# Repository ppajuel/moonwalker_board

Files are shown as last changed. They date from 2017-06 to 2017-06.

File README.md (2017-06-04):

# moonwalker_board
Expansion board compatible with [Raspberry Pi 1 Modelo B](https://www.raspberrypi.org/products/model-b/)
 and [IGEP NEW YORK](https://isee.biz/products/igep-expansion-boards/igep-new-york) to control a RC CAR. Board Layout has been adapted to suite with [Nikko Mega Dominator](http://nikkoevolution.fr/voitures_et_pieces/568/Nikko-Mega-Dominator.html), but can be easily adaptable to another RC Car. Its features are:

* ATmega328 microcontroller: control all expansion board functionalities.
* Raspberry or IGEP boards (optional): control microcontroller through serial port.
* GPS expansion bus: [Adafruit Ultimate GPS Breakout](https://www.adafruit.com/product/746).
* Compass and accelerometer expansion bus: [Triple-axis Accelerometer+Magnetometer (Compass) Board - LSM303)](https://www.adafruit.com/product/1120).
* Gauge battery circuit.
* Servo and brushed motor drivers.
* Two independent power trees for electric motors and sensors&control.
* Atmega programer header.
* Hex segment display.

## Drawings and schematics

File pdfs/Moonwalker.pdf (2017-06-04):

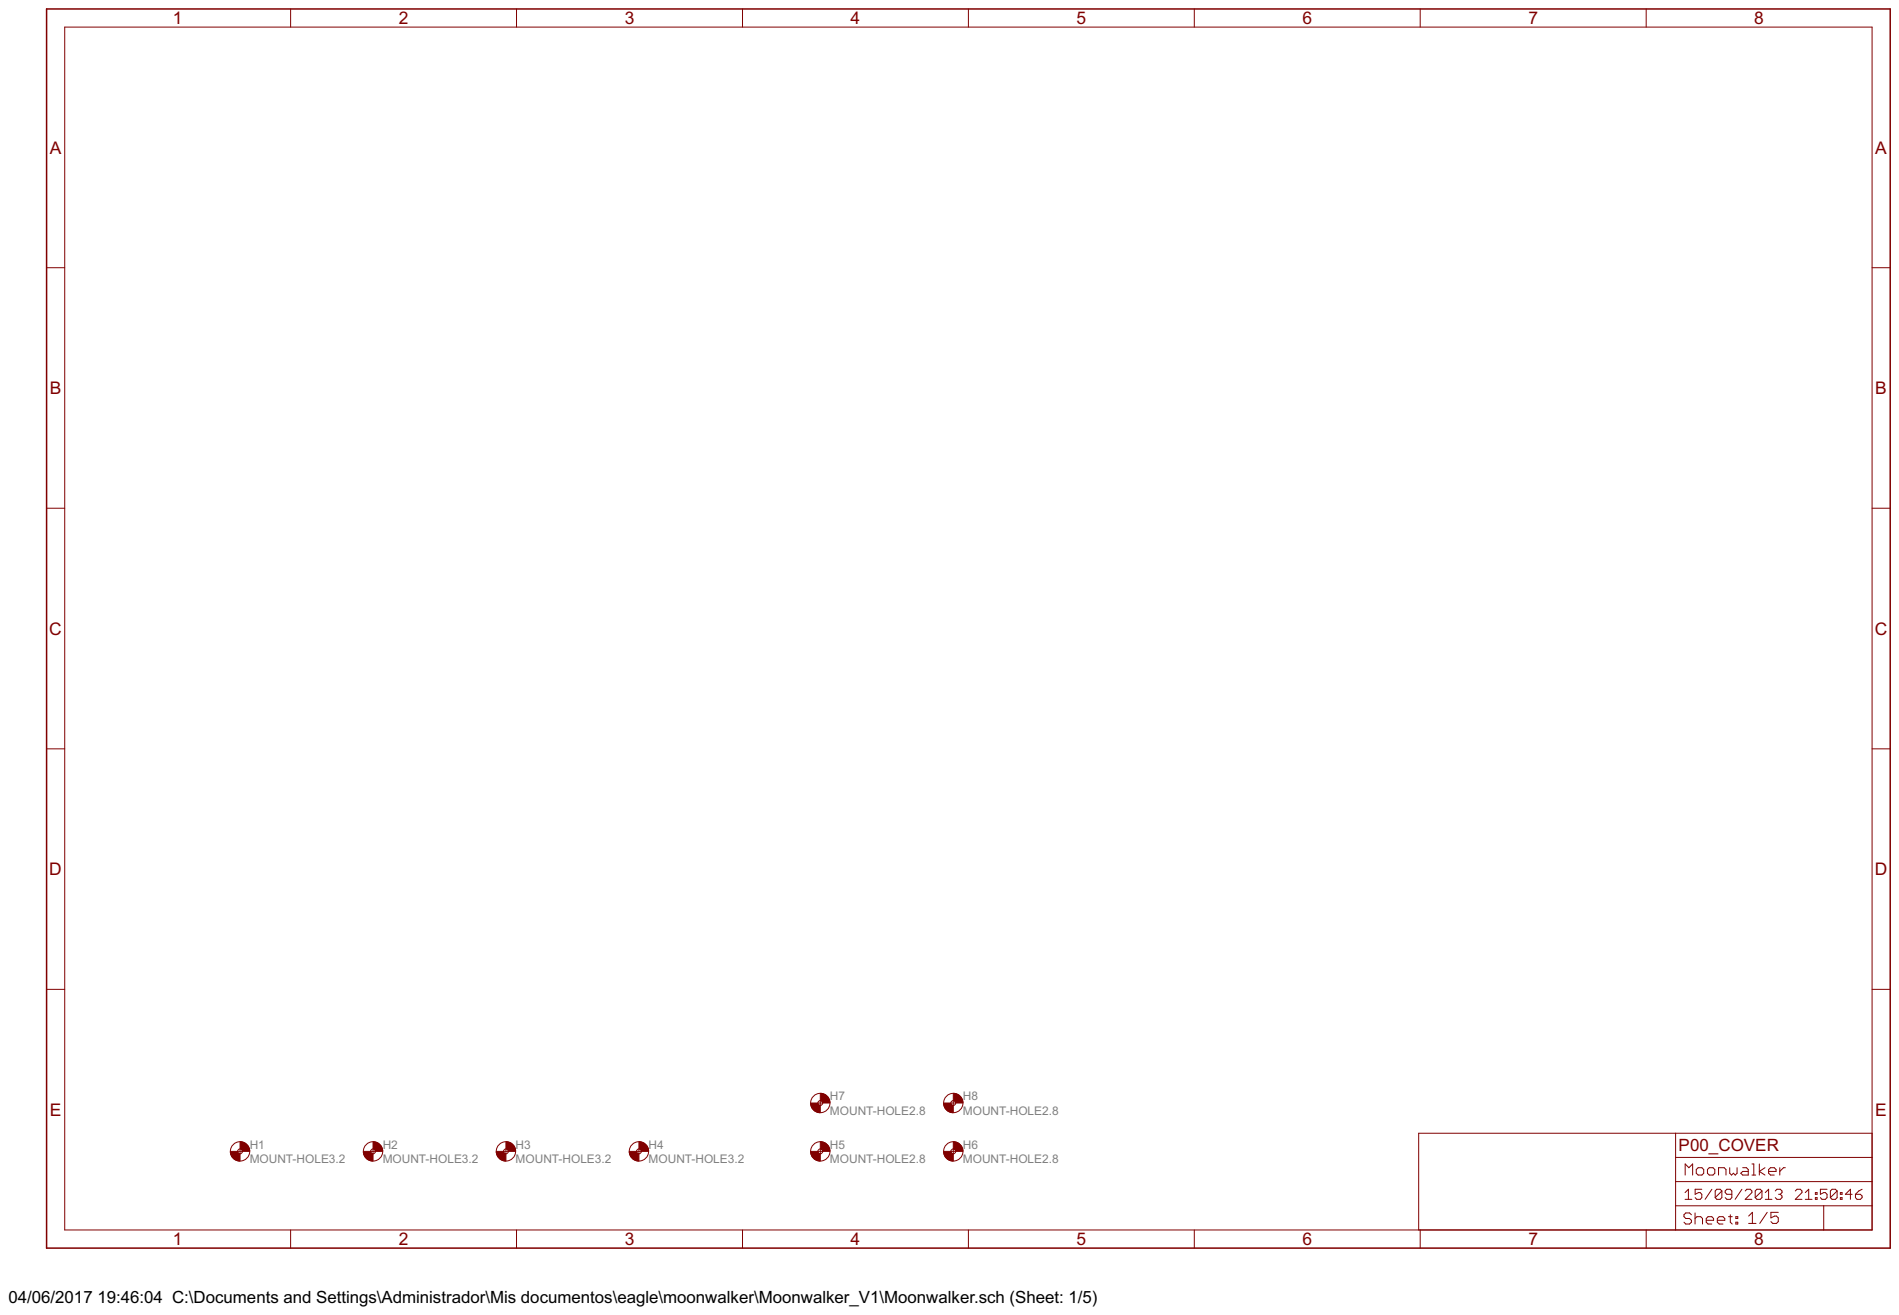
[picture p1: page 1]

04/06/2017 19:46:04 C:\Documents and Settings\Administrador\Mis documentos\eagle\moonwalker\Moonwalker_V1\Moonwalker.sch (Sheet: 1/5)

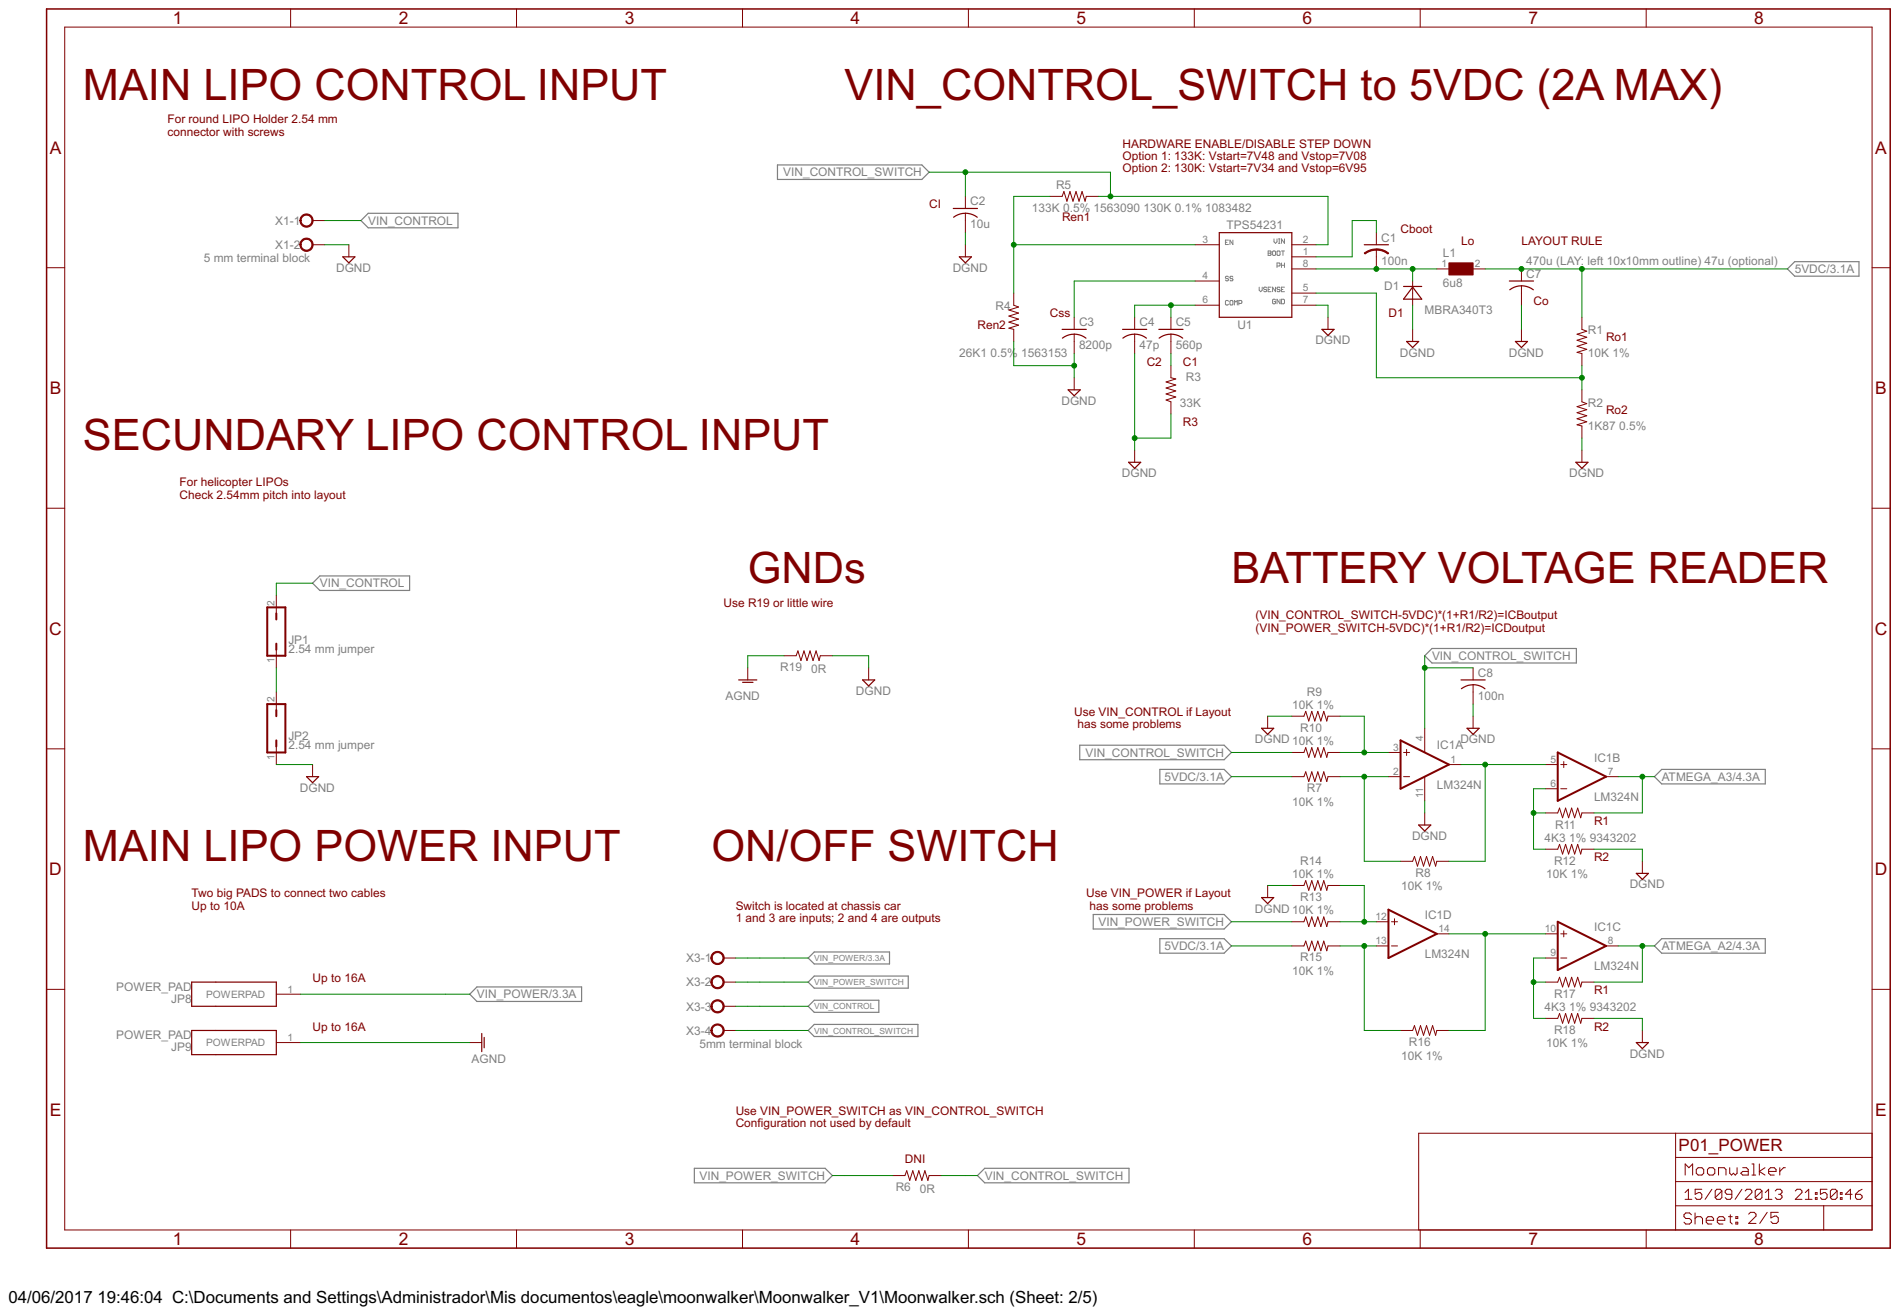
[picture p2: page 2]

MAIN LIPO CONTROL INPUT

For round LIPO Holder 2.54 mm
connector with screws

HARDWARE ENABLE/DISABLE STEP DOWN
Option 1: 133K: Vstart=7V48 and Vstop=7V08
Option 2: 130K: Vstart=7V34 and Vstop=6V95

LAYOUT RULE
470u (LAY: left 10x10mm outline) 47u (optional)

SECUNDARY LIPO CONTROL INPUT

For helicopter LIPOs Check 2.54mm pitch into layout

Use R19 or little wire

MAIN LIPO POWER INPUT

Two big PADS to connect two cables Up to 10A

1 and 3 are inputs; 2 and 4 are outputs

Use VIN_POWER_SWITCH as VIN_CONTROL_SWITCH
Configuration not used by default

04/06/2017 19:46:04 C:\Documents and Settings\Administrador\Mis documentos\eagle\moonwalker\Moonwalker_V1\Moonwalker.sch (Sheet: 2/5)

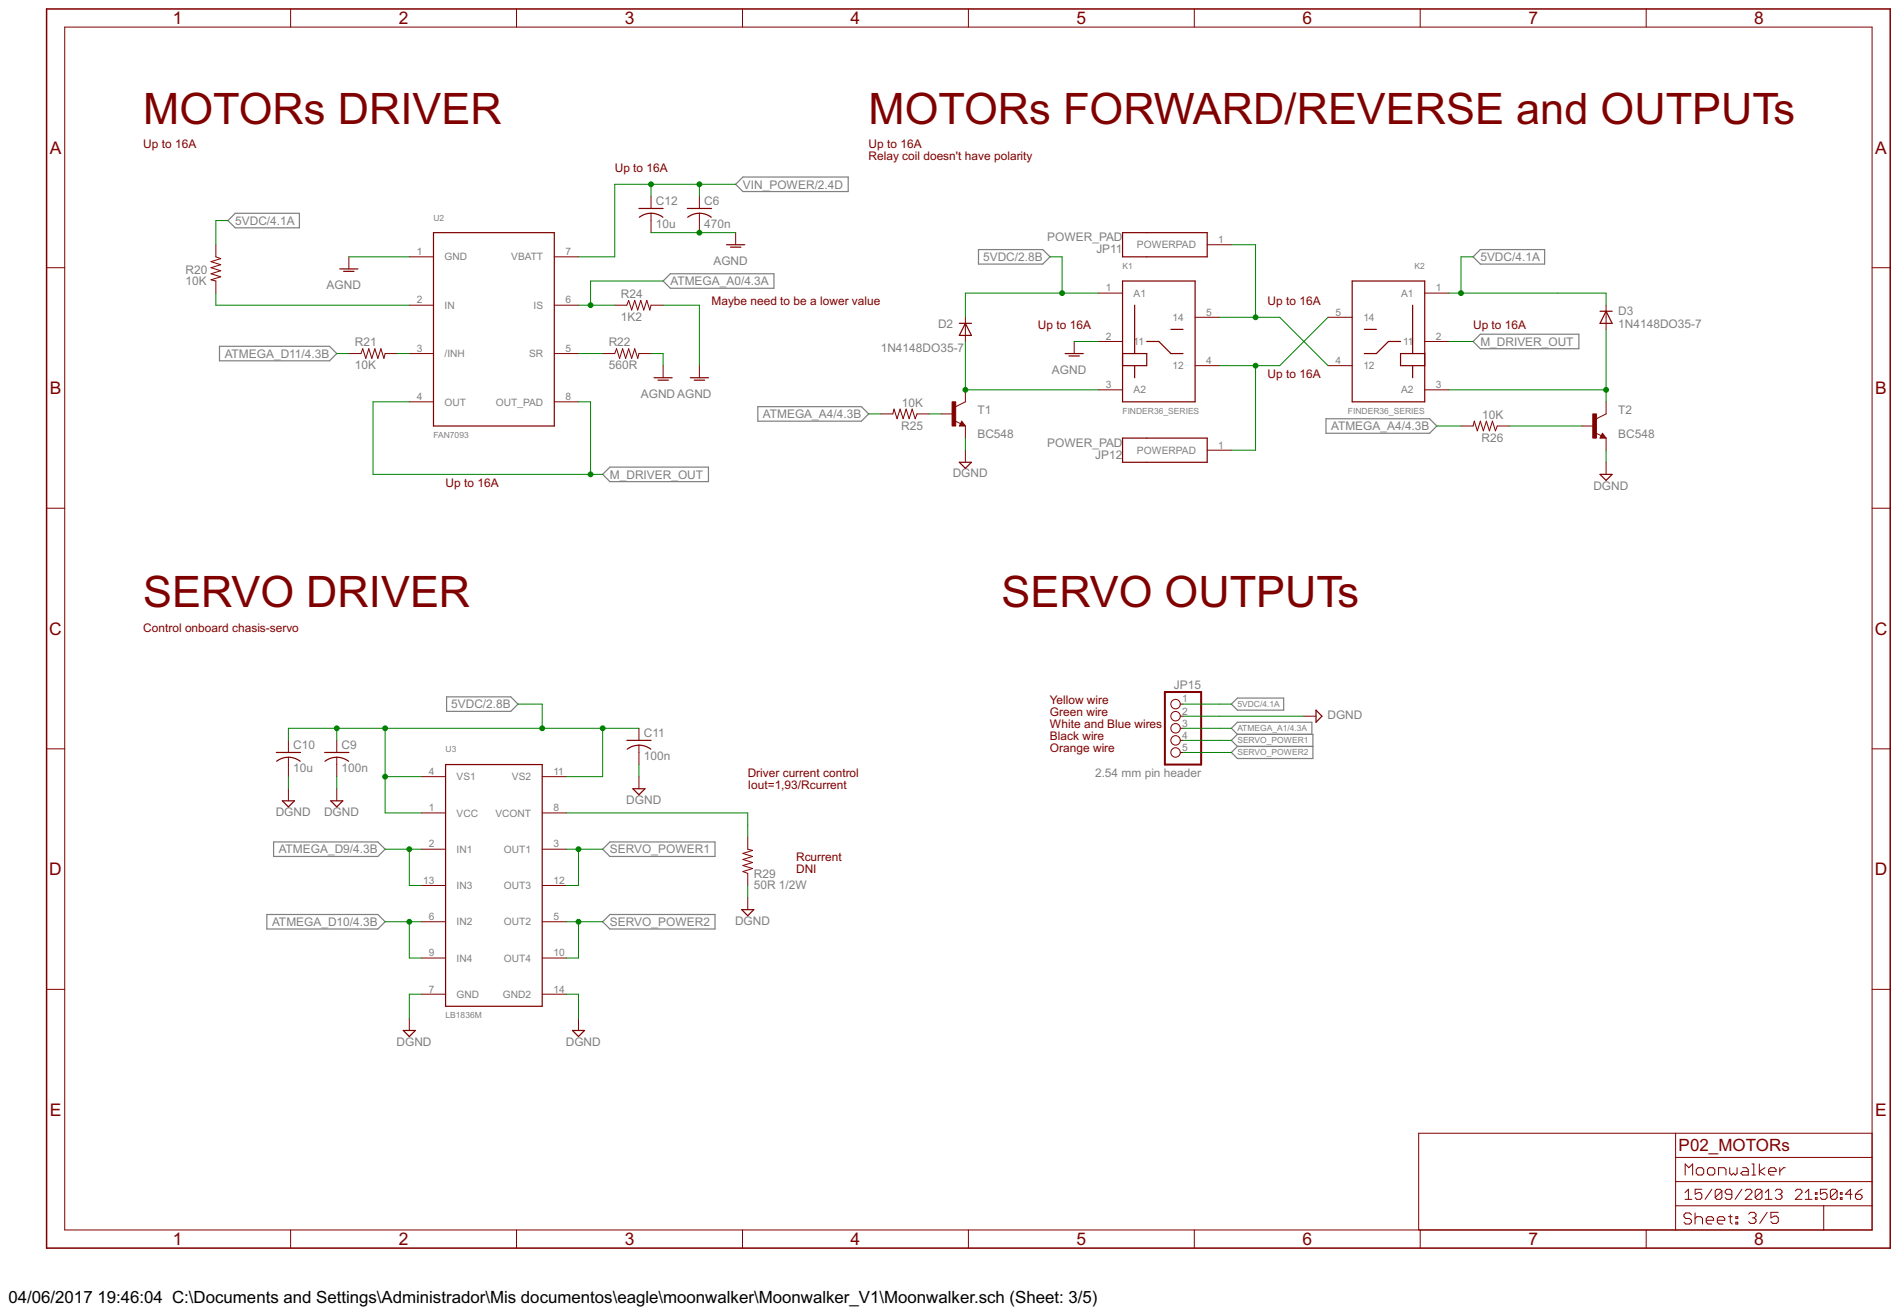
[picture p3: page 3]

MOTORs FORWARD/REVERSE and OUTPUTs

Relay coil doesn't have polarity

Maybe need to be a lower value

Control onboard chasis-servo

Yellow wire Green wire White and Blue wires Black wire Orange wire

04/06/2017 19:46:04 C:\Documents and Settings\Administrador\Mis documentos\eagle\moonwalker\Moonwalker_V1\Moonwalker.sch (Sheet: 3/5)

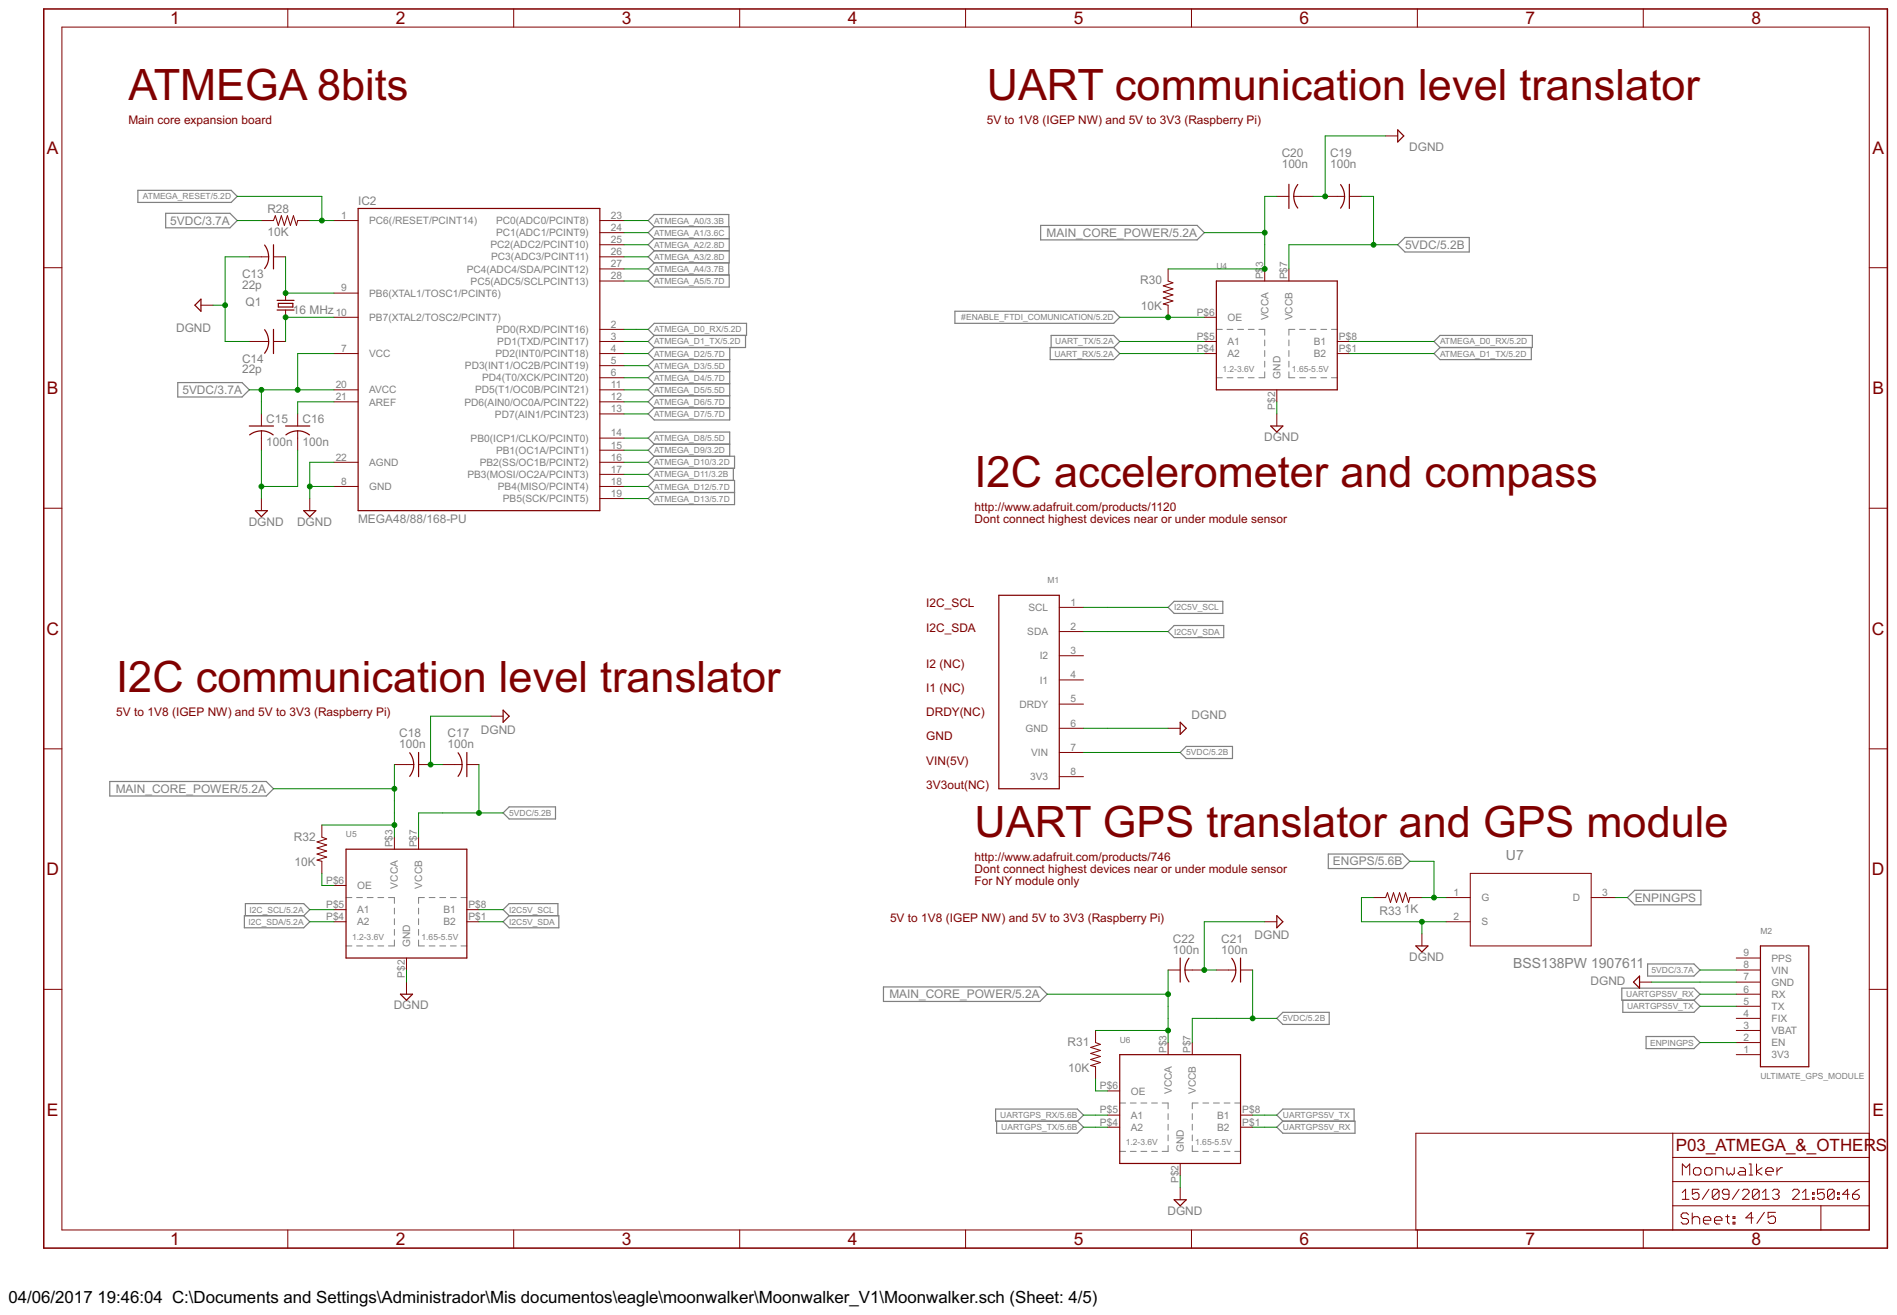
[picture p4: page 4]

UART communication level translator

Main core expansion board

5V to 1V8 (IGEP NW) and 5V to 3V3 (Raspberry Pi)

http://www.adafruit.com/products/1120
Dont connect highest devices near or under module sensor

GND
UART GPS translator and GPS module

http://www.adafruit.com/products/746
Dont connect highest devices near or under module sensor For NY module only

04/06/2017 19:46:04 C:\Documents and Settings\Administrador\Mis documentos\eagle\moonwalker\Moonwalker_V1\Moonwalker.sch (Sheet: 4/5)

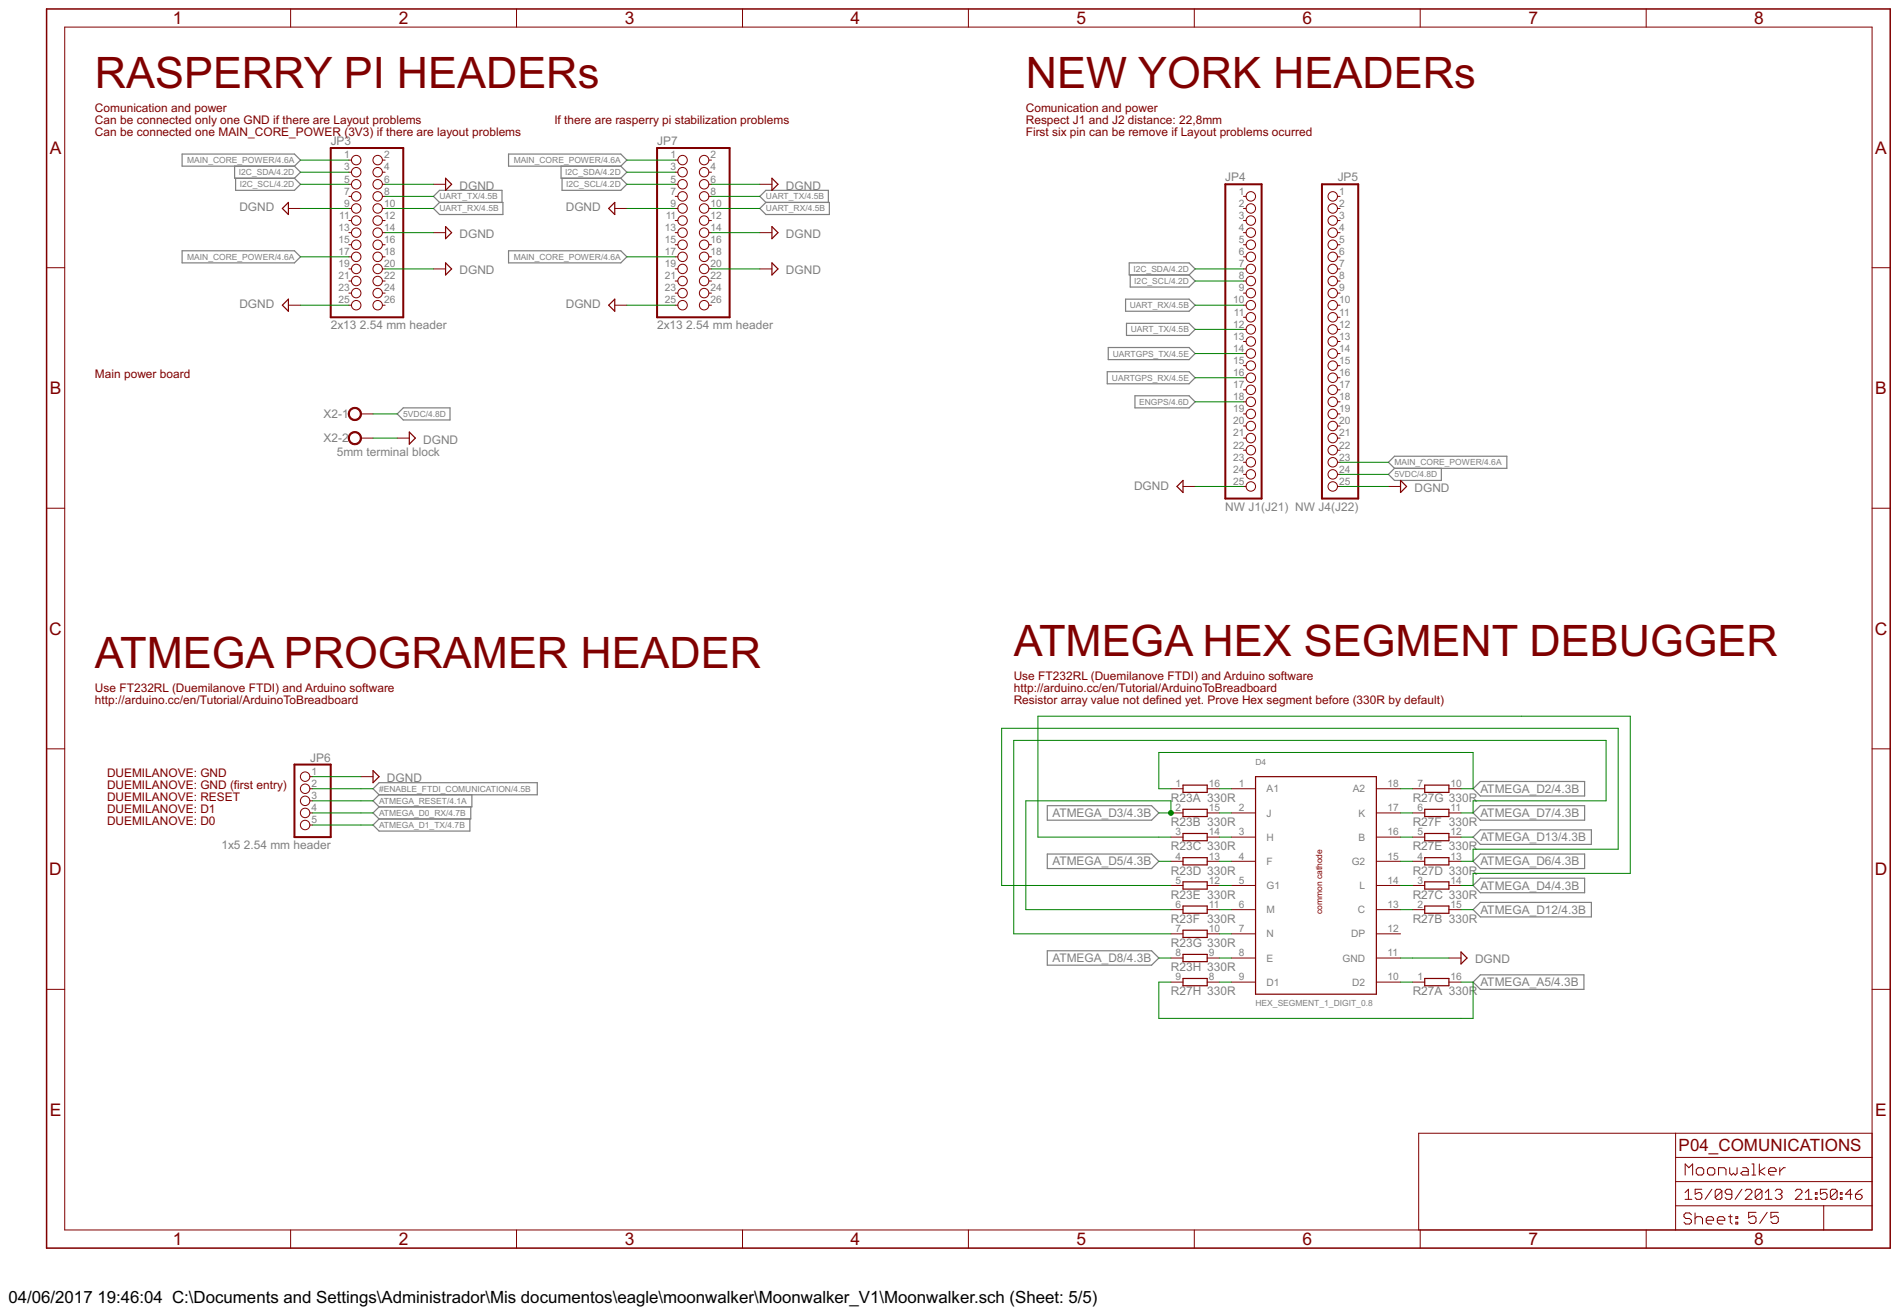
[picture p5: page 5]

If there are rasperry pi stabilization problems A

Can be connected only one GND if there are Layout problems Can be connected one MAIN_CORE_POWER (3V3) if there are layout problems

Comunication and power
Respect J1 and J2 distance: 22,8mm
First six pin can be remove if Layout problems ocurred

ATMEGA HEX SEGMENT DEBUGGER

Use FT232RL (Duemilanove FTDI) and Arduino software
http://arduino.cc/en/Tutorial/ArduinoToBreadboard
Resistor array value not defined yet. Prove Hex segment before (330R by default)

DUEMILANOVE: GND
DUEMILANOVE: GND (first entry)
DUEMILANOVE: RESET
DUEMILANOVE: D1
DUEMILANOVE: D0

04/06/2017 19:46:04 C:\Documents and Settings\Administrador\Mis documentos\eagle\moonwalker\Moonwalker_V1\Moonwalker.sch (Sheet: 5/5)

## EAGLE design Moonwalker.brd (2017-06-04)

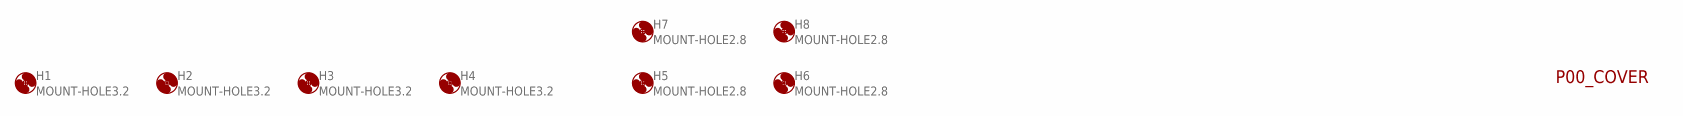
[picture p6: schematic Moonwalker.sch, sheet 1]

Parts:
H1, H2, H3, H4: MOUNT-HOLE3.2; 3,2
H5, H6, H7, H8: MOUNT-HOLE2.8; 2,8

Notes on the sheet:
P00_COVER

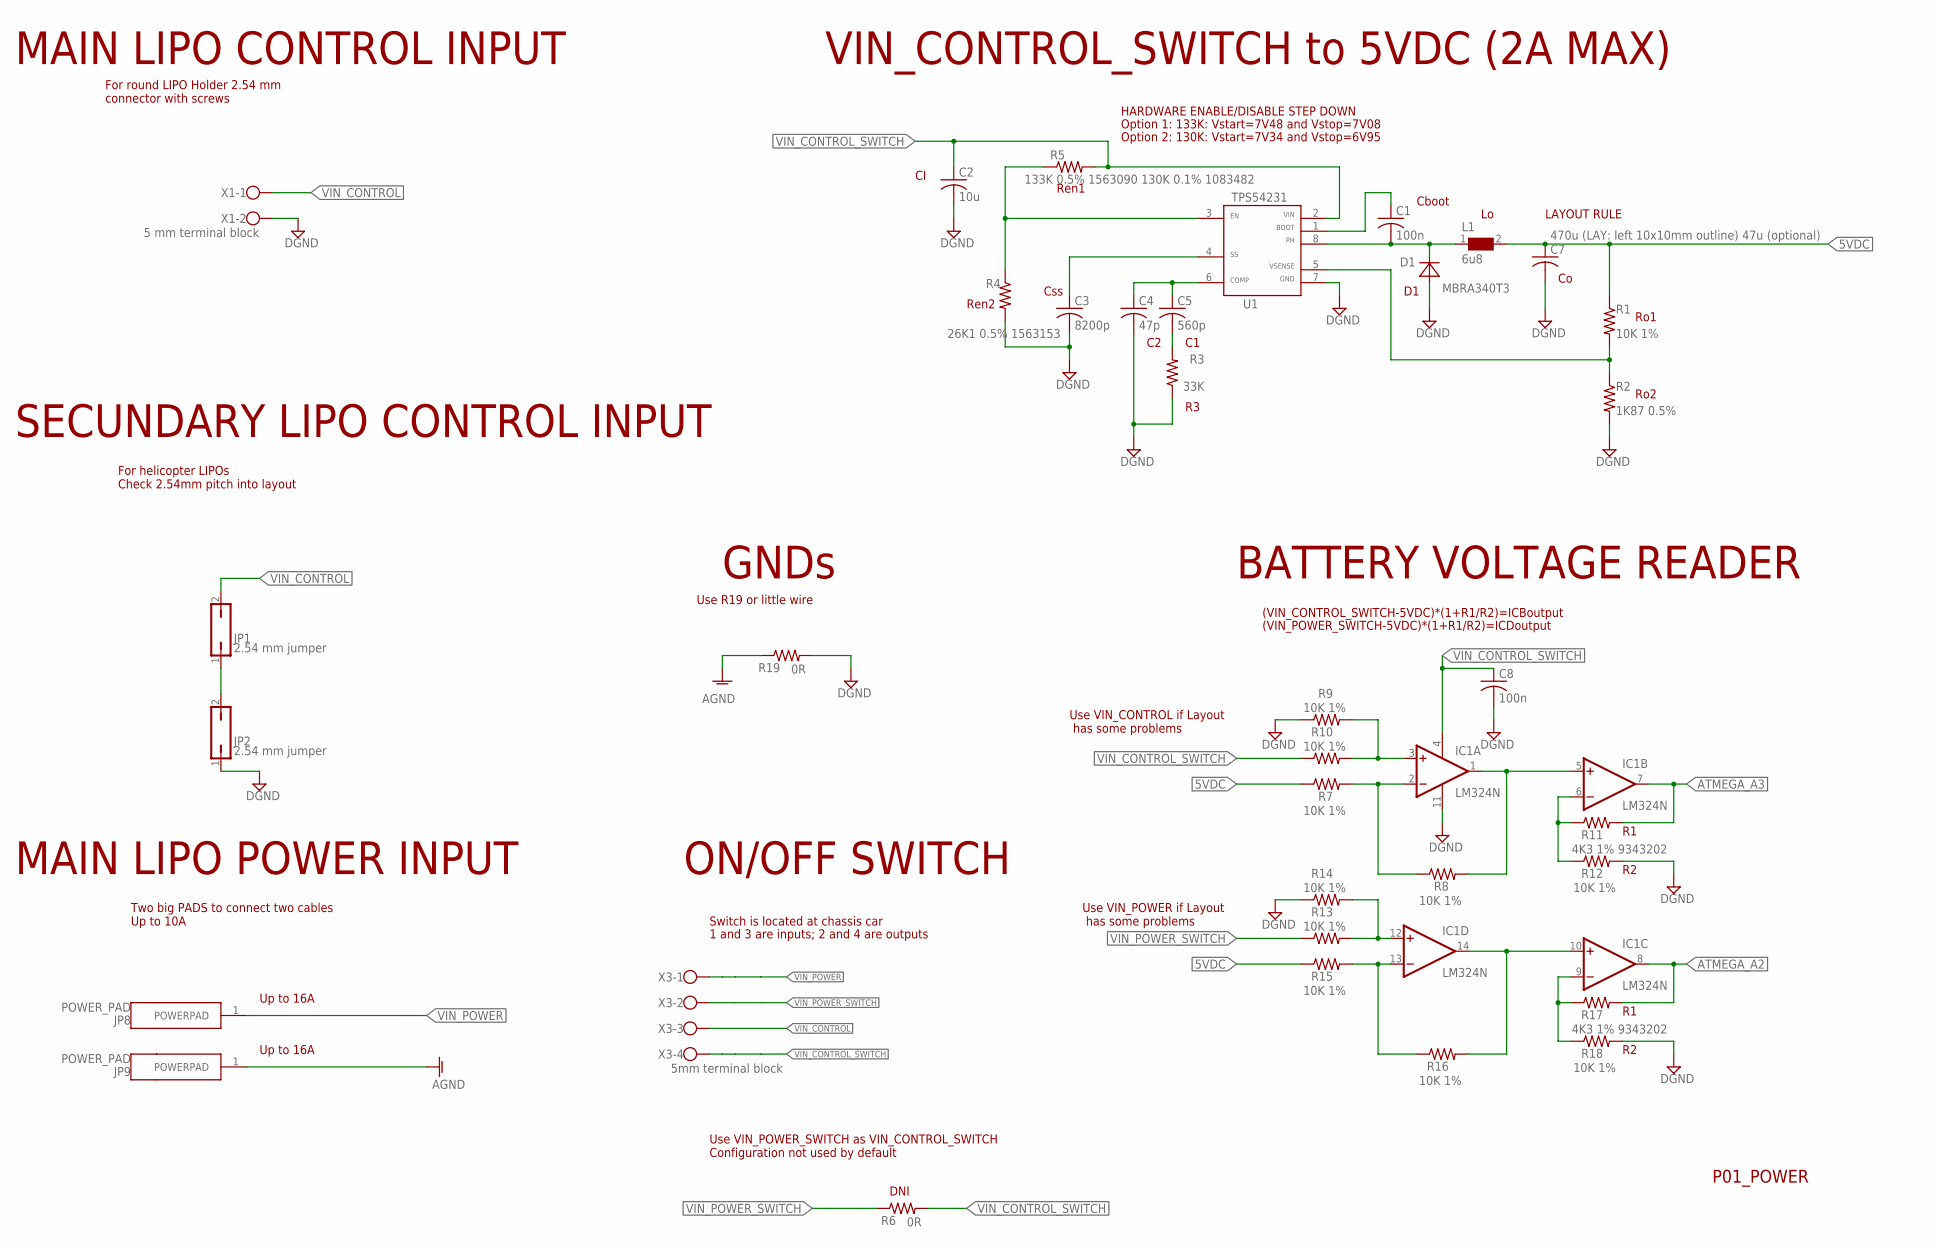
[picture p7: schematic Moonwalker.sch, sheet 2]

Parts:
C1: 100n; C075-032X103
C2: 10u; C025-050X050
C3: 8200p; C1206
C4: 47p; C050-024X044
C5: 560p; C1206
C7: 470u (LAY: left 10x10mm outline) 47u (optional); C050-075X075
C8: 100n; C050-024X044
D1: MBRA340T3; SMA
IC1: LM324N; DIL14
JP1, JP2: 2.54 mm jumper; JP1
JP8, JP9: POWER_PAD
L1: 6u8; WE-PD_7332/7345_PLASTIC_BASE
R1, R7, R8, R9, R10, R12, R13, R14, R15, R16, R18: 10K 1%; 0309/10
R2: 1K87 0.5%; 0309/10
R3: 33K; 0309/10
R4: 26K1 0.5% 1563153; 0309/10
R5: 133K 0.5% 1563090 130K 0.1% 1083482; 0309/10
R6, R19: 0R; 0309/10
R11, R17: 4K3 1% 9343202; 0309/10
U1: TPS54231SO8; SO8
X1: 5 mm terminal block; W237-102
X3: 5mm terminal block; W237-4

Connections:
5VDC: C7.1, L1.2, R1.1, R7.1, R15.1; also elsewhere on the board
AGND: JP9.1, R19.1; also elsewhere on the board
ATMEGA_A2: IC1.8 (OUT), R17.2; also elsewhere on the board
ATMEGA_A3: IC1.7 (OUT), R11.2; also elsewhere on the board
DGND: C2.2, C3.2, C4.2, C7.2, C8.2, D1.A, IC1.11 (V-), JP2.1, R2.2, R3.1, R4.2, R9.1, R12.2, R14.1, R18.2, R19.2, U1.7, X1.2; also elsewhere on the board
unnamed: C4.1, C5.1, U1.6
unnamed: C5.2, R3.2
unnamed: R4.1, R5.1, U1.3
unnamed: C3.1, U1.4
unnamed: C1.2, D1.C, L1.1, U1.8
unnamed: C1.1, U1.1
unnamed: R1.2, R2.1, U1.5
unnamed: JP1.1, JP2.2
unnamed: IC1.3 (+IN), R9.2, R10.2
unnamed: IC1.2 (-IN), R7.2, R8.1
unnamed: IC1.12 (+IN), R13.2, R14.2
unnamed: IC1.13 (-IN), R15.2, R16.1
unnamed: IC1.10 (+IN), IC1.14 (OUT), R16.2
unnamed: IC1.1 (OUT), IC1.5 (+IN), R8.2
unnamed: IC1.6 (-IN), R11.1, R12.1
unnamed: IC1.9 (-IN), R17.1, R18.1
VIN_CONTROL: JP1.2, X1.1, X3.3
VIN_CONTROL_SWITCH: C2.1, C8.1, IC1.4 (V+), R5.2, R6.2, R10.1, U1.2, X3.4
VIN_POWER: JP8.1, X3.1; also elsewhere on the board
VIN_POWER_SWITCH: R6.1, R13.1, X3.2

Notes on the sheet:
P01_POWER
Cboot
VIN_CONTROL_SWITCH to 5VDC (2A MAX)
Option 2: 130K: Vstart=7V34 and Vstop=6V95
Option 1: 133K: Vstart=7V48 and Vstop=7V08
HARDWARE ENABLE/DISABLE STEP DOWN
Ren2
Ren1
Css
Ro1
Ro2
MAIN LIPO CONTROL INPUT
SECUNDARY LIPO CONTROL INPUT
For round LIPO Holder 2.54 mm connector with screws
For helicopter LIPOs Check 2.54mm pitch into layout
MAIN LIPO POWER INPUT
Two big PADS to connect two cables Up to 10A
Use VIN_POWER_SWITCH as VIN_CONTROL_SWITCH Configuration not used by default
DNI
BATTERY VOLTAGE READER
ON/OFF SWITCH
(VIN_CONTROL_SWITCH-5VDC)*(1+R1/R2)=ICBoutput
(VIN_POWER_SWITCH-5VDC)*(1+R1/R2)=ICDoutput
GNDs
Switch is located at chassis car
Use VIN_POWER if Layout has some problems
Use VIN_CONTROL if Layout has some problems
Up to 16A
LAYOUT RULE
Use R19 or little wire
1 and 3 are inputs; 2 and 4 are outputs

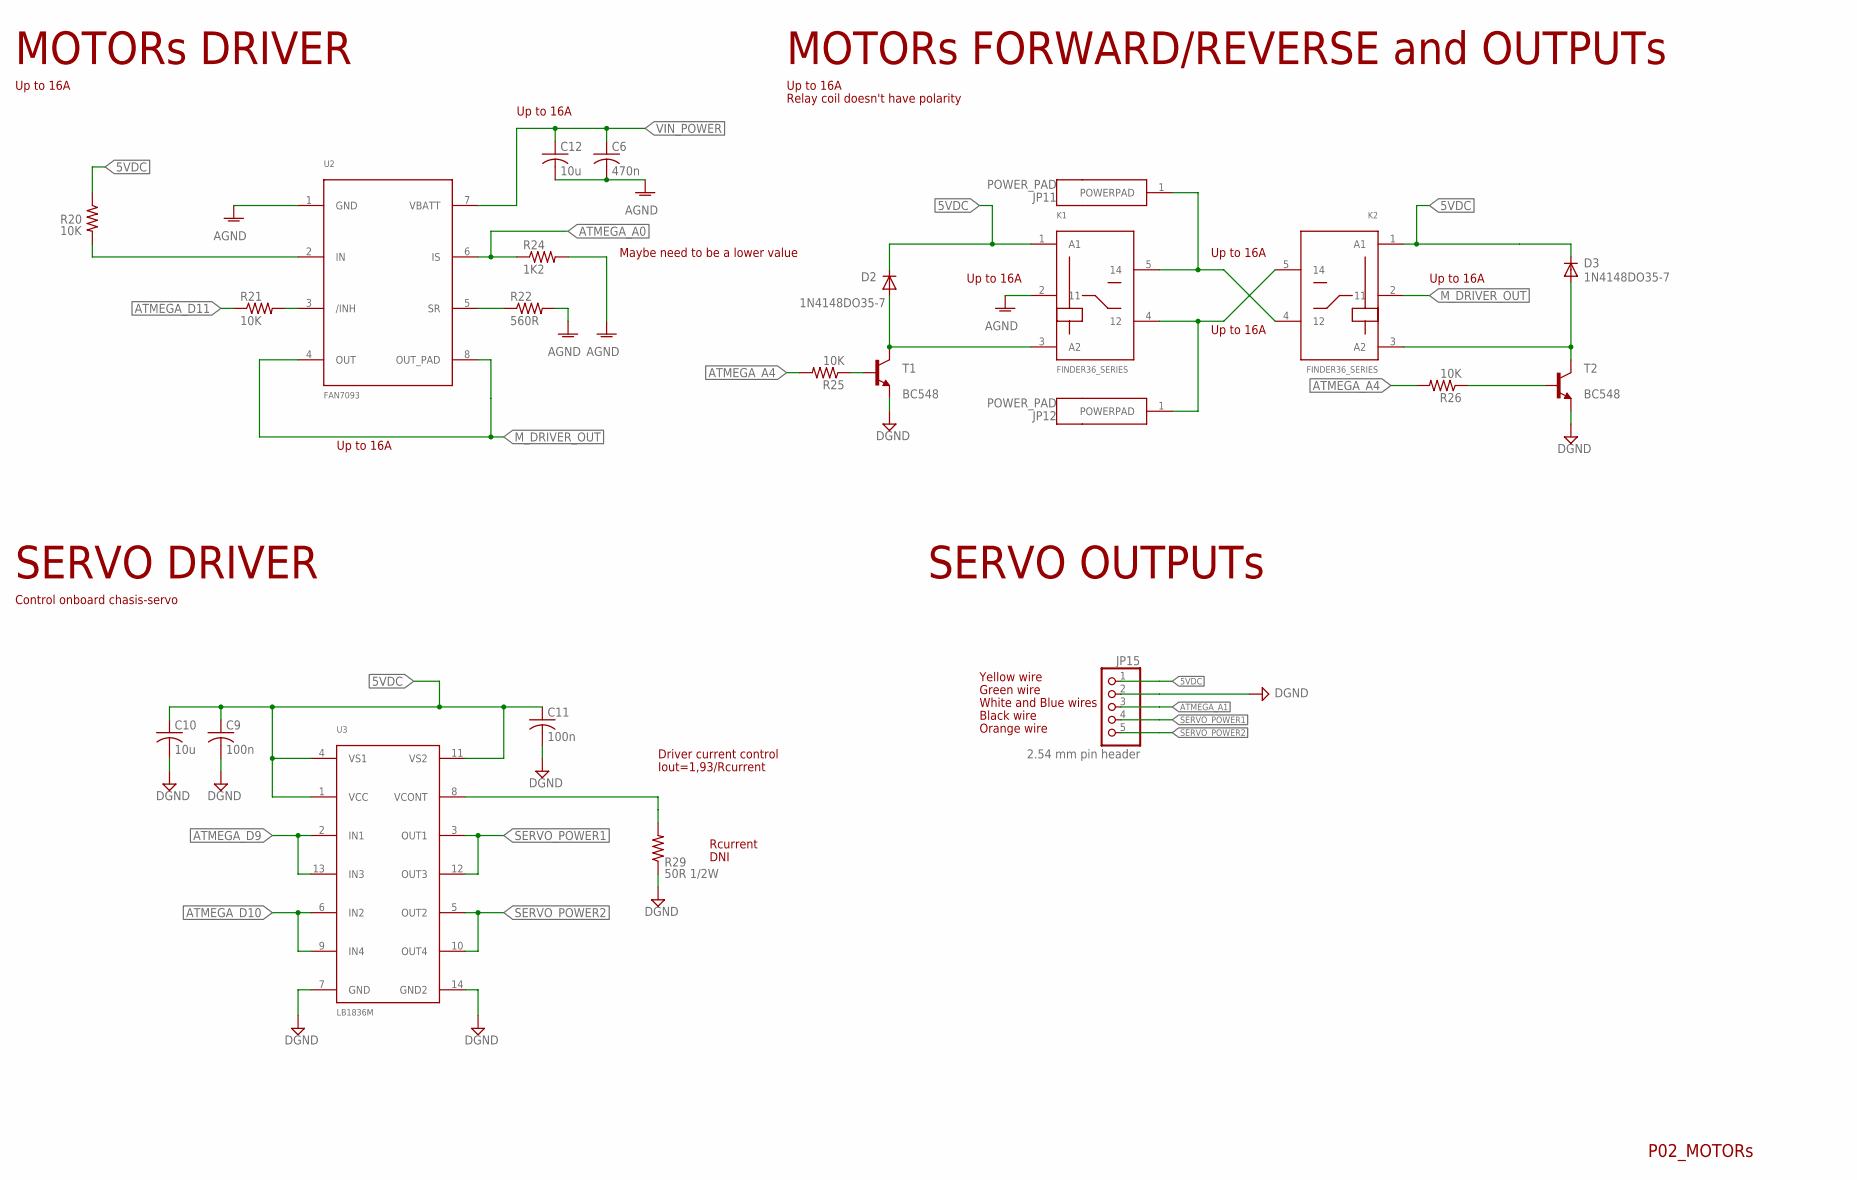
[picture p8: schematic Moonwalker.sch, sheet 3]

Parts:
C6: 470n; C050-050X075
C9, C11: 100n; C050-024X044
C10, C12: 10u; C025-050X050
D2, D3: 1N4148DO35-7; DO35-7
JP11, JP12: POWER_PAD
JP15: 2.54 mm pin header; 1X05/90
K1, K2: FINDER36_SERIES; FINDERSERIE36
R20, R21, R25, R26: 10K; 0309/10
R22: 560R; 0309/10
R24: 1K2; 0411/12
R29: 50R 1/2W; 0411/12
T1, T2: BC548; TO92-CBE
U2: FAN7093; TO263
U3: LB1836M; SOIC14W

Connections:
5VDC: C9.1, C10.1, C11.1, D2.C, D3.C, JP15.1, K1.1 (A1), K2.1 (A1), R20.1, U3.1 (VCC), U3.4 (VS1), U3.11 (VS2); also elsewhere on the board
AGND: C6.2, C12.2, K1.2 (11), R22.2, R24.2, U2.1 (GND); also elsewhere on the board
ATMEGA_A0: R24.1, U2.6 (IS); also elsewhere on the board
ATMEGA_A1: JP15.3; also elsewhere on the board
ATMEGA_A4: R25.2, R26.2; also elsewhere on the board
ATMEGA_D9: U3.2 (IN1), U3.13 (IN3); also elsewhere on the board
ATMEGA_D10: U3.6 (IN2), U3.9 (IN4); also elsewhere on the board
ATMEGA_D11: R21.1; also elsewhere on the board
DGND: C9.2, C10.2, C11.2, JP15.2, R29.1, T1.E, T2.E, U3.7 (GND), U3.14 (GND2); also elsewhere on the board
M_DRIVER_OUT: K2.2 (11), U2.4 (OUT), U2.8 (OUT_PAD)
unnamed: R29.2, U3.8 (VCONT)
unnamed: JP11.1, K1.5 (14), K2.4 (12)
unnamed: R22.1, U2.5 (SR)
unnamed: R20.2, U2.2 (IN)
unnamed: R21.2, U2.3 (/INH)
unnamed: JP12.1, K1.4 (12), K2.5 (14)
unnamed: D2.A, K1.3 (A2), T1.C
unnamed: D3.A, K2.3 (A2), T2.C
unnamed: R26.1, T2.B
unnamed: R25.1, T1.B
SERVO_POWER1: JP15.4, U3.3 (OUT1), U3.12 (OUT3)
SERVO_POWER2: JP15.5, U3.5 (OUT2), U3.10 (OUT4)
VIN_POWER: C6.1, C12.1, U2.7 (VBATT); also elsewhere on the board

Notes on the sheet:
P02_MOTORs
MOTORs DRIVER
Up to 16A
MOTORs FORWARD/REVERSE and OUTPUTs
SERVO DRIVER
Control onboard chasis-servo
Driver current control
Iout=1,93/Rcurrent
Rcurrent
DNI
SERVO OUTPUTs
Yellow wire
Green wire
White and Blue wires
Black wire
Orange wire
Maybe need to be a lower value
Relay coil doesn't have polarity

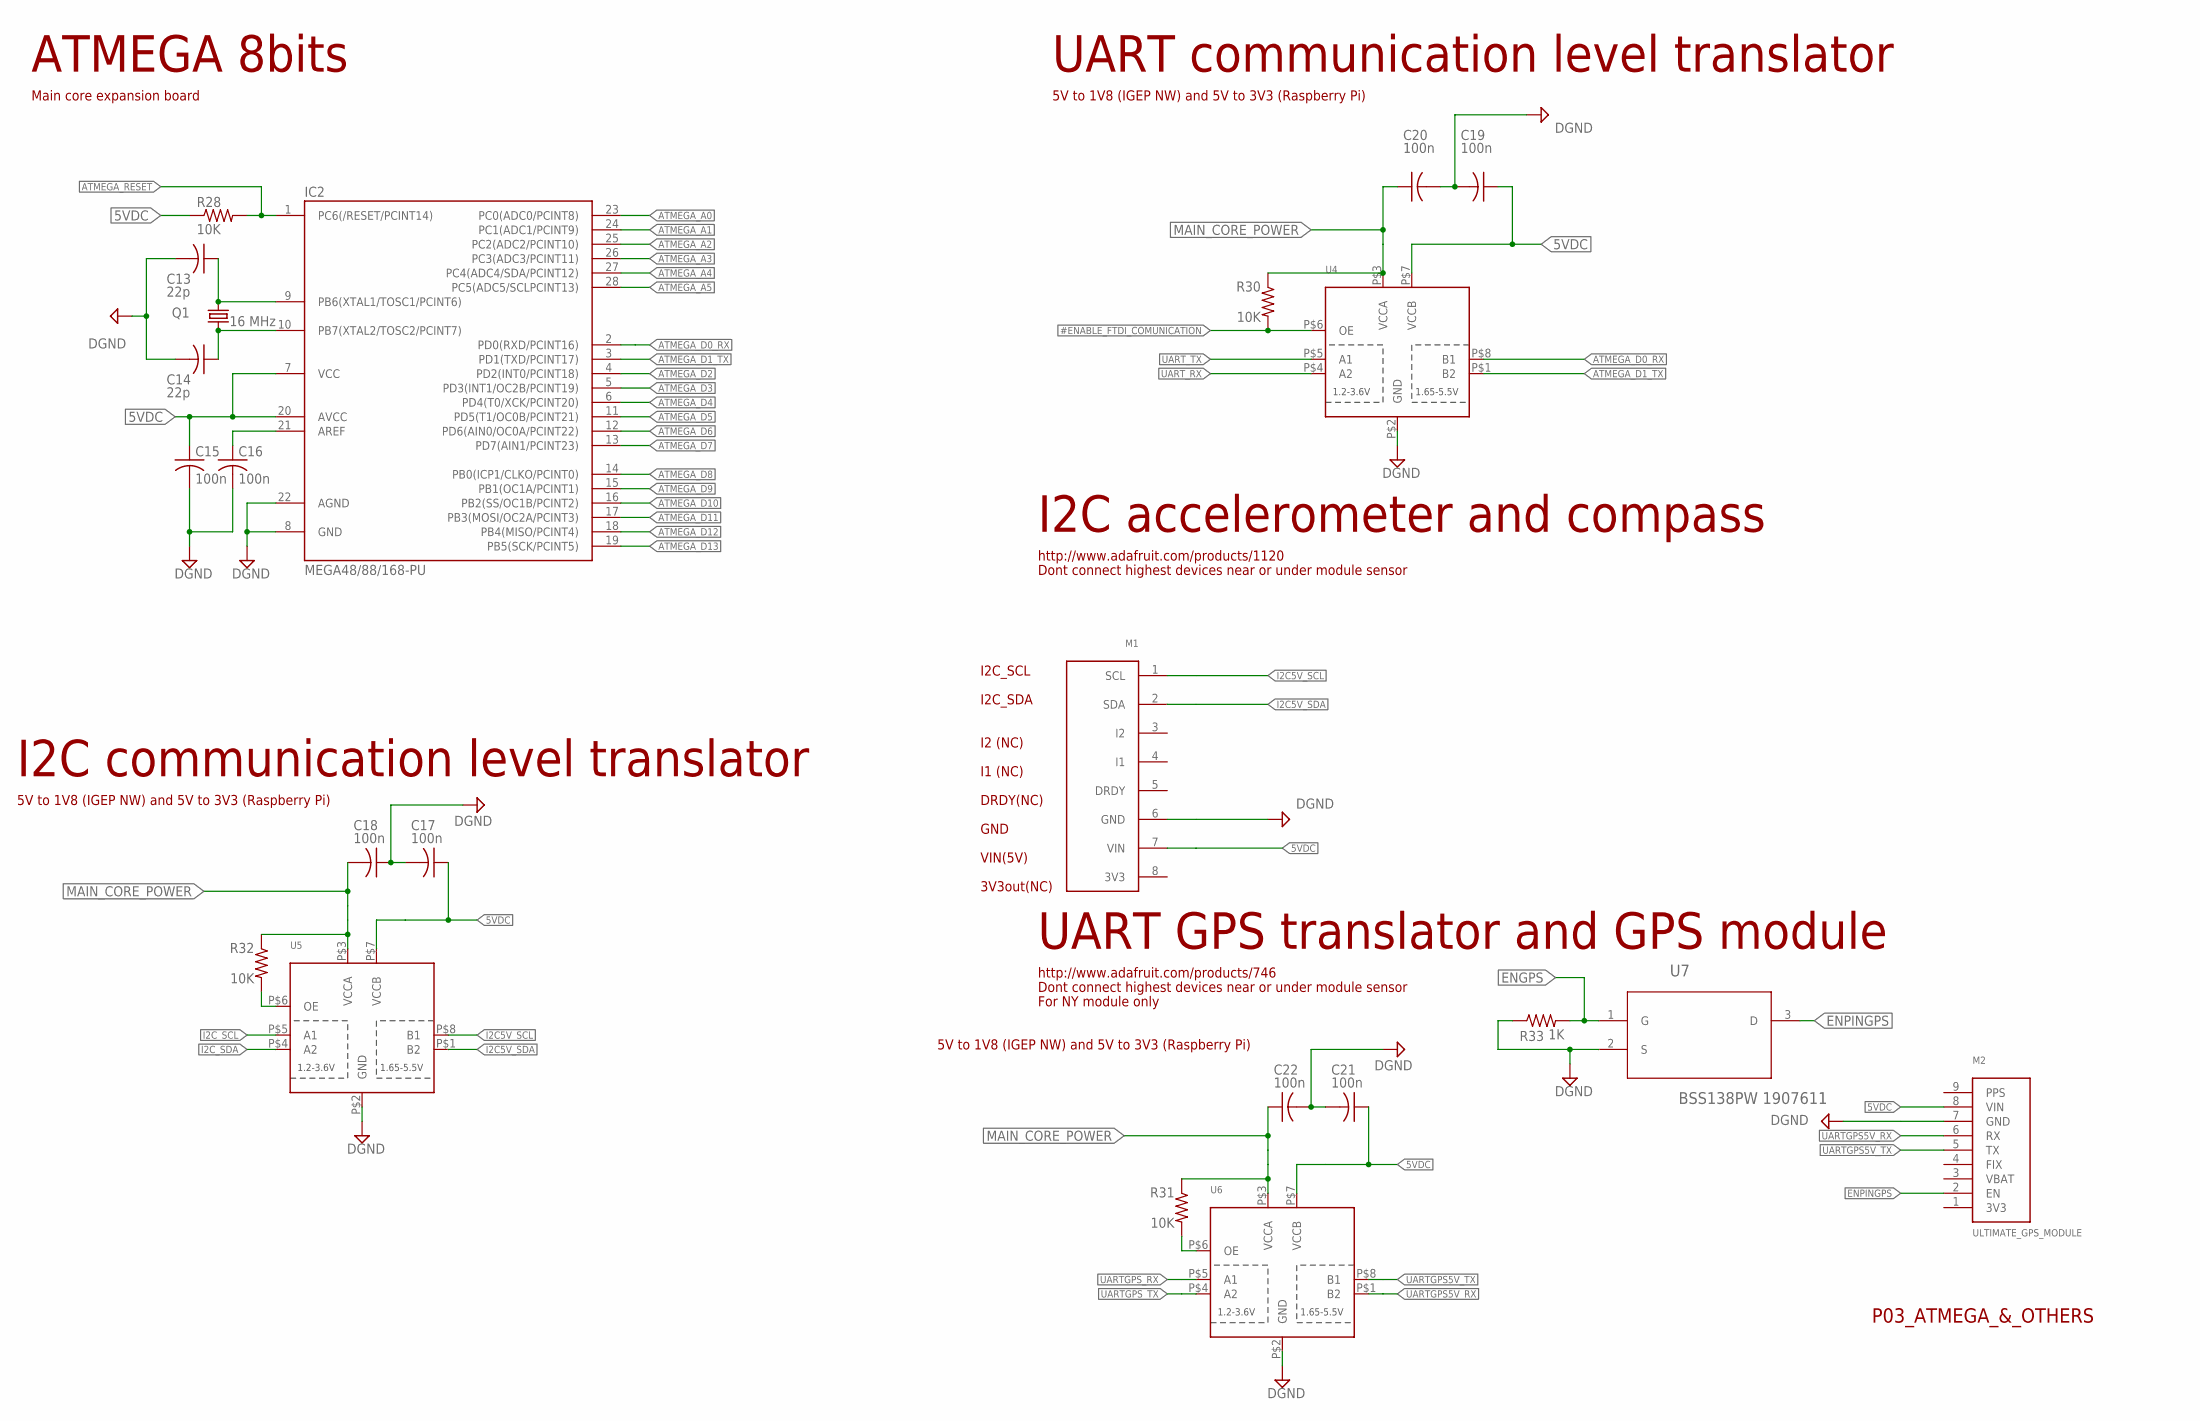
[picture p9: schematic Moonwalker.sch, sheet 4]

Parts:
C13, C14: 22p; C050-024X044
C15, C16, C17, C18, C19, C20, C21, C22: 100n; C050-024X044
IC2: MEGA48/88/168-PU; DIL28-3
M1: COMPASS_&_ACCELEROMETER_ADAFRUIT_LSM303
M2: ULTIMATE_GPS_MODULE
Q1: 16 MHz; HC49/S
R28, R30, R31, R32: 10K; 0309/10
R33: 1K; 0309/10
U4, U5, U6: TXS0102; VFSOP-8
U7: BSS138PW 1907611; SOT65P210X110-3N

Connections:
5VDC: C15.1, C17.1, C19.1, C21.1, IC2.7 (VCC), IC2.20 (AVCC), M1.7 (VIN), M2.8 (VIN), R28.1, U4.P$7 (VCCB), U5.P$7 (VCCB), U6.P$7 (VCCB); also elsewhere on the board
#ENABLE_FTDI_COMUNICATION: R30.2, U4.P$6 (OE); also elsewhere on the board
ATMEGA_A0: IC2.23 (PC0(ADC0/PCINT8)); also elsewhere on the board
ATMEGA_A1: IC2.24 (PC1(ADC1/PCINT9)); also elsewhere on the board
ATMEGA_A2: IC2.25 (PC2(ADC2/PCINT10)); also elsewhere on the board
ATMEGA_A3: IC2.26 (PC3(ADC3/PCINT11)); also elsewhere on the board
ATMEGA_A4: IC2.27 (PC4(ADC4/SDA/PCINT12)); also elsewhere on the board
ATMEGA_A5: IC2.28 (PC5(ADC5/SCLPCINT13)); also elsewhere on the board
ATMEGA_D0_RX: IC2.2 (PD0(RXD/PCINT16)), U4.P$8 (B1); also elsewhere on the board
ATMEGA_D1_TX: IC2.3 (PD1(TXD/PCINT17)), U4.P$1 (B2); also elsewhere on the board
ATMEGA_D2: IC2.4 (PD2(INT0/PCINT18)); also elsewhere on the board
ATMEGA_D3: IC2.5 (PD3(INT1/OC2B/PCINT19)); also elsewhere on the board
ATMEGA_D4: IC2.6 (PD4(T0/XCK/PCINT20)); also elsewhere on the board
ATMEGA_D5: IC2.11 (PD5(T1/OC0B/PCINT21)); also elsewhere on the board
ATMEGA_D6: IC2.12 (PD6(AIN0/OC0A/PCINT22)); also elsewhere on the board
ATMEGA_D7: IC2.13 (PD7(AIN1/PCINT23)); also elsewhere on the board
ATMEGA_D8: IC2.14 (PB0(ICP1/CLKO/PCINT0)); also elsewhere on the board
ATMEGA_D9: IC2.15 (PB1(OC1A/PCINT1)); also elsewhere on the board
ATMEGA_D10: IC2.16 (PB2(SS/OC1B/PCINT2)); also elsewhere on the board
ATMEGA_D11: IC2.17 (PB3(MOSI/OC2A/PCINT3)); also elsewhere on the board
ATMEGA_D12: IC2.18 (PB4(MISO/PCINT4)); also elsewhere on the board
ATMEGA_D13: IC2.19 (PB5(SCK/PCINT5)); also elsewhere on the board
ATMEGA_RESET: IC2.1 (PC6(/RESET/PCINT14)), R28.2; also elsewhere on the board
DGND: C13.2, C14.2, C15.2, C16.2, C17.2, C18.1, C19.2, C20.2, C21.2, C22.2, IC2.8 (GND), IC2.22 (AGND), M1.6 (GND), M2.7 (GND), R33.1, U4.P$2 (GND), U5.P$2 (GND), U6.P$2 (GND), U7.2 (S); also elsewhere on the board
ENGPS: R33.2, U7.1 (G); also elsewhere on the board
ENPINGPS: M2.2 (EN), U7.3 (D)
I2C5V_SCL: M1.1 (SCL), U5.P$8 (B1)
I2C5V_SDA: M1.2 (SDA), U5.P$1 (B2)
I2C_SCL: U5.P$5 (A1); also elsewhere on the board
I2C_SDA: U5.P$4 (A2); also elsewhere on the board
MAIN_CORE_POWER: C18.2, C20.1, C22.1, R30.1, R31.1, R32.1, U4.P$3 (VCCA), U5.P$3 (VCCA), U6.P$3 (VCCA); also elsewhere on the board
unnamed: C13.1, IC2.9 (PB6(XTAL1/TOSC1/PCINT6)), Q1.2
unnamed: C14.1, IC2.10 (PB7(XTAL2/TOSC2/PCINT7)), Q1.1
unnamed: C16.1, IC2.21 (AREF)
unnamed: R32.2, U5.P$6 (OE)
unnamed: R31.2, U6.P$6 (OE)
UARTGPS5V_RX: M2.6 (RX), U6.P$1 (B2)
UARTGPS5V_TX: M2.5 (TX), U6.P$8 (B1)
UARTGPS_RX: U6.P$5 (A1); also elsewhere on the board
UARTGPS_TX: U6.P$4 (A2); also elsewhere on the board
UART_RX: U4.P$4 (A2); also elsewhere on the board
UART_TX: U4.P$5 (A1); also elsewhere on the board

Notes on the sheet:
P03_ATMEGA_&_OTHERS
ATMEGA 8bits
Main core expansion board
UART communication level translator
5V to 1V8 (IGEP NW) and 5V to 3V3 (Raspberry Pi)
I2C communication level translator
I2C accelerometer and compass
http://www.adafruit.com/products/1120
Dont connect highest devices near or under module sensor
I2C_SCL
I2C_SDA
I2 (NC)
I1 (NC)
DRDY(NC)
GND
VIN(5V)
3V3out(NC)
UART GPS translator and GPS module
http://www.adafruit.com/products/746
For NY module only

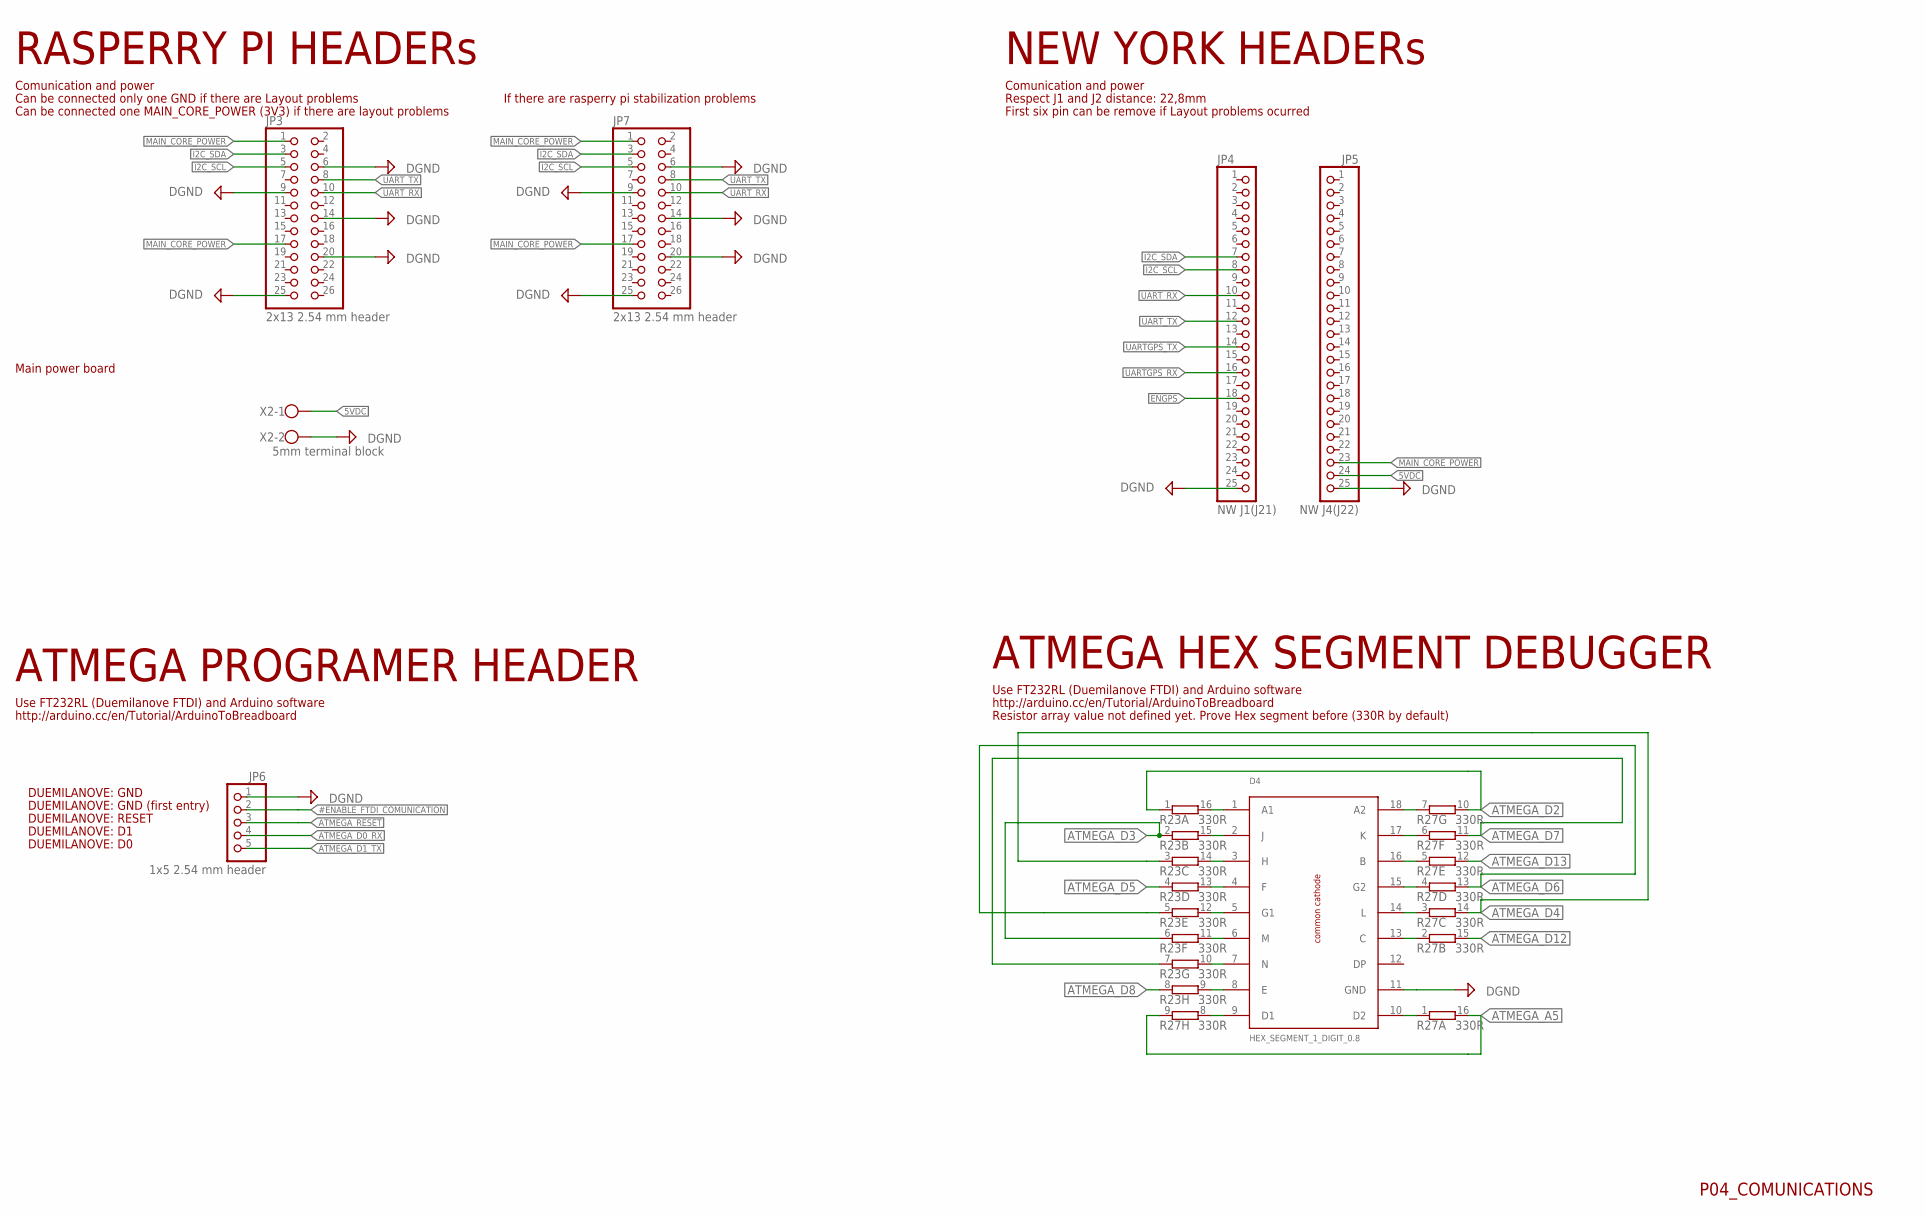
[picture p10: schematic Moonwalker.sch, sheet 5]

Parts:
D4: HEX_SEGMENT_1_DIGIT_0.8
JP3, JP7: 2x13 2.54 mm header; 2X13
JP4: NW J1(J21); 1X25
JP5: NW J4(J22); 1X25
JP6: 1x5 2.54 mm header; 1X05/90
R23, R27: 330R; 4816P
X2: 5mm terminal block; W237-102

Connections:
5VDC: JP5.24, X2.1; also elsewhere on the board
#ENABLE_FTDI_COMUNICATION: JP6.2; also elsewhere on the board
ATMEGA_A5: R27.9 (2), R27.16 (2); also elsewhere on the board
ATMEGA_D0_RX: JP6.4; also elsewhere on the board
ATMEGA_D1_TX: JP6.5; also elsewhere on the board
ATMEGA_D2: R23.1, R27.10 (2); also elsewhere on the board
ATMEGA_D3: R23.2 (1), R23.6 (1); also elsewhere on the board
ATMEGA_D4: R23.3 (1), R27.14 (2); also elsewhere on the board
ATMEGA_D5: R23.4 (1); also elsewhere on the board
ATMEGA_D6: R23.5 (1), R27.13 (2); also elsewhere on the board
ATMEGA_D7: R23.7 (1), R27.11 (2); also elsewhere on the board
ATMEGA_D8: R23.8 (1); also elsewhere on the board
ATMEGA_D12: R27.15 (2); also elsewhere on the board
ATMEGA_D13: R27.12 (2); also elsewhere on the board
ATMEGA_RESET: JP6.3; also elsewhere on the board
DGND: D4.11 (GND), JP3.6, JP3.9, JP3.14, JP3.20, JP3.25, JP4.25, JP5.25, JP6.1, JP7.6, JP7.9, JP7.14, JP7.20, JP7.25, X2.2; also elsewhere on the board
ENGPS: JP4.18; also elsewhere on the board
I2C_SCL: JP3.5, JP4.8, JP7.5; also elsewhere on the board
I2C_SDA: JP3.3, JP4.7, JP7.3; also elsewhere on the board
MAIN_CORE_POWER: JP3.1, JP3.17, JP5.23, JP7.1, JP7.17; also elsewhere on the board
unnamed: D4.9 (D1), R27.8 (1)
unnamed: D4.1 (A1), R23.16 (2)
unnamed: D4.13 (C), R27.2 (1)
unnamed: D4.2 (J), R23.15 (2)
unnamed: D4.3 (H), R23.14 (2)
unnamed: D4.4 (F), R23.13 (2)
unnamed: D4.5 (G1), R23.12 (2)
unnamed: D4.10 (D2), R27.1
unnamed: D4.6 (M), R23.11 (2)
unnamed: D4.7 (N), R23.10 (2)
unnamed: D4.8 (E), R23.9 (2)
unnamed: D4.18 (A2), R27.7 (1)
unnamed: D4.17 (K), R27.6 (1)
unnamed: D4.16 (B), R27.5 (1)
unnamed: D4.15 (G2), R27.4 (1)
unnamed: D4.14 (L), R27.3 (1)
UARTGPS_RX: JP4.16; also elsewhere on the board
UARTGPS_TX: JP4.14; also elsewhere on the board
UART_RX: JP3.10, JP4.10, JP7.10; also elsewhere on the board
UART_TX: JP3.8, JP4.12, JP7.8; also elsewhere on the board

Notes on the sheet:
P04_COMUNICATIONS
RASPERRY PI HEADERs
Comunication and power
NEW YORK HEADERs
Main power board
Respect J1 and J2 distance: 22,8mm
ATMEGA PROGRAMER HEADER
Use FT232RL (Duemilanove FTDI) and Arduino software
http://arduino.cc/en/Tutorial/ArduinoToBreadboard
First six pin can be remove if Layout problems ocurred
ATMEGA HEX SEGMENT DEBUGGER
DUEMILANOVE: D1
DUEMILANOVE: RESET
DUEMILANOVE: GND
DUEMILANOVE: GND (first entry)
DUEMILANOVE: D0
Can be connected only one GND if there are Layout problems
Can be connected one MAIN_CORE_POWER (3V3) if there are layout problems
Resistor array value not defined yet. Prove Hex segment before (330R by default)
If there are rasperry pi stabilization problems

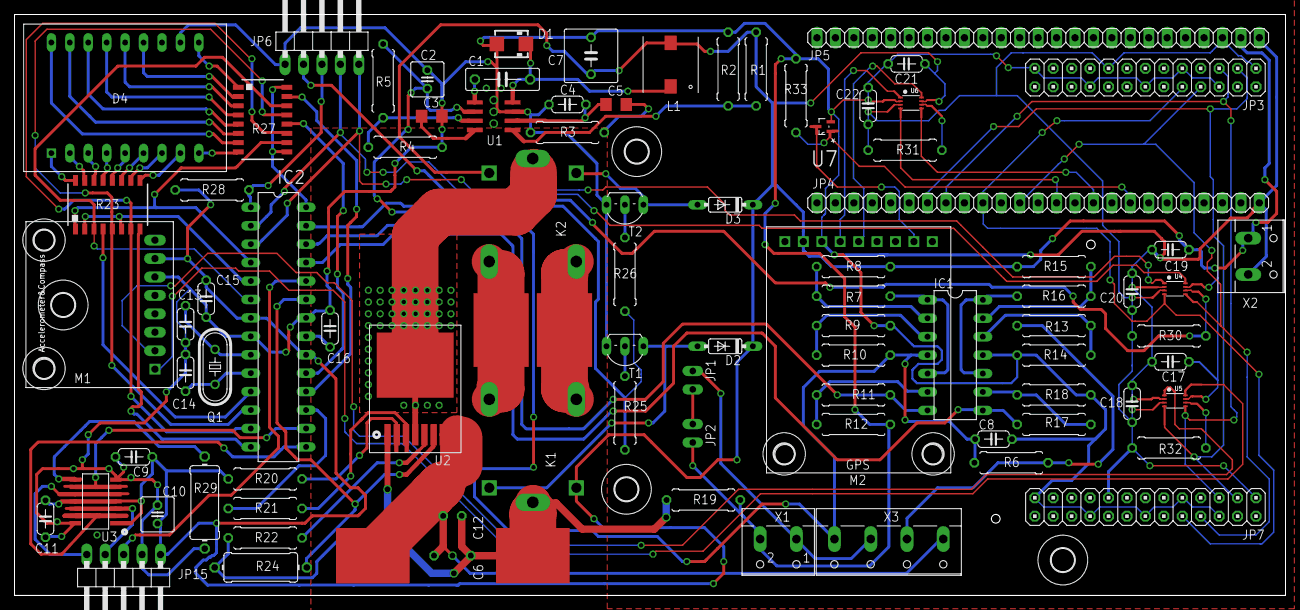
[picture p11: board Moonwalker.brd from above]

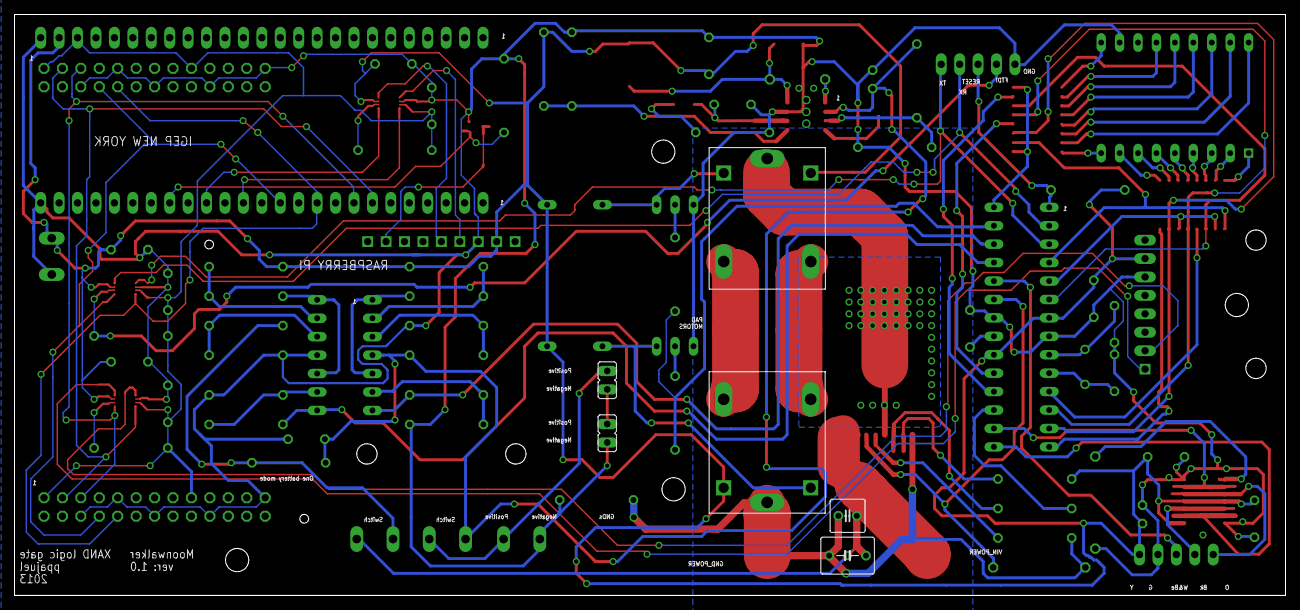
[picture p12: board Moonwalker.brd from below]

Board: 2 copper layers, 175.2 x 80.1 mm, 99 parts (6 on the bottom side), 92 nets.

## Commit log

2017-06-04 First schematic and layout release
    sch and brd files contain Eagle schematic and layout respectively
    [Moonwalker.brd, Moonwalker.sch]
2017-06-04 Add gerbers for release one
    [Moonwalker.drl]
2017-06-04 Add schematic pdf for release one
